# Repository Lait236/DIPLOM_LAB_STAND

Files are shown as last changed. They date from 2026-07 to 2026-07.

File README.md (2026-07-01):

В DIPLOM_LAB_STAND_SCHEMES находятся принципиальные схемы стенда и разводки плат в вариантах с модулями (с использованием заливки земли полигоном ..._gnd или без заливки) и без них (тоже с заливкой полигоном и без неё).

DIPLOM.kicad_sch - Принципиальная схема управляющей платы.

пс_плата_2.kicad_sch - Принципиальная платы расширенной периферии.

DIPLOM.kicad_pcb - Разводка управляющей платы.

DIPLOM_BOARD2.kicad_pcb - Разводка платы расширенной периферии.

В DIPLOM_LAB_STAND находятся файлы проекта для Microchip Studio. 

В DEBUG находится .hex файл для прошивки микроконтроллера. 

DIPLOM_LAB_STAND.atsln - сам проект.

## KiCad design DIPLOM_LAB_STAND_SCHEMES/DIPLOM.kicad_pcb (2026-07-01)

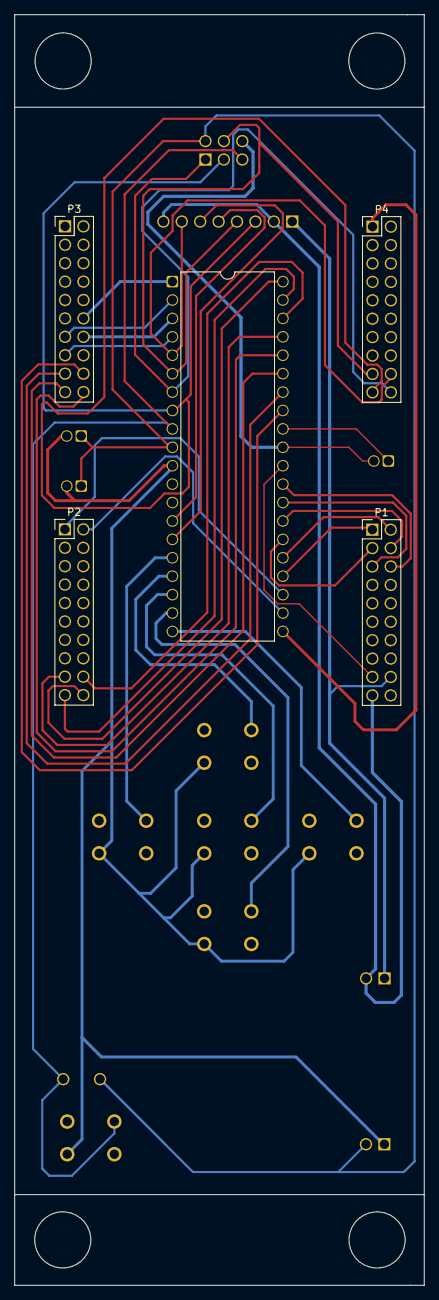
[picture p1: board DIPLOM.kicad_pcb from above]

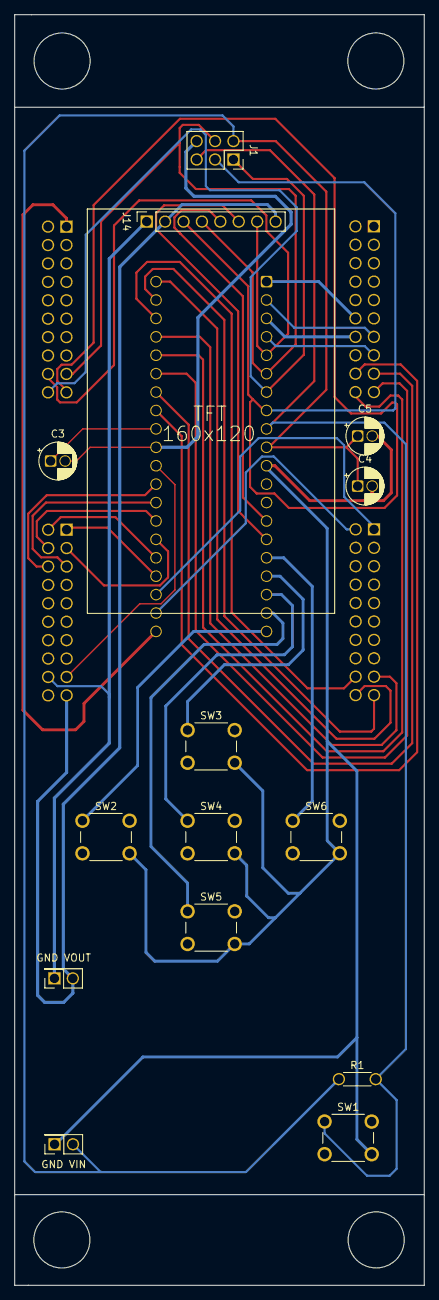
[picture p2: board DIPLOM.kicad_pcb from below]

Board: 2 copper layers, 56.5 x 150.0 mm, 19 parts (14 on the bottom side), 37 nets.

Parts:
C3, C5: 0.1uF; CP_Radial_D5.0mm_P2.00mm
C4: 10uF; CP_Radial_D5.0mm_P2.00mm
GND VIN: PinSocket_2x01_P2.54mm_Vertical
GND VOUT: PinSocket_2x01_P2.54mm_Vertical
J1: USBASP_PINS; PinSocket_2x03_P2.54mm_Vertical
J14: display_out; PinSocket_1x08_P2.54mm_Vertical
P1, P2, P3, P4: PinHeader_2x10_P2.54mm_Vertical
R1: 10k; R_Axial_DIN0204_L3.6mm_D1.6mm_P5.08mm_Horizontal
SW1: BTN_RST; SW_PUSH_6mm
SW2: BTN_L; SW_PUSH_6mm
SW3: BTN_UP; SW_PUSH_6mm
SW4: BTN_CENTER; SW_PUSH_6mm
SW5: BTN_DOWN; SW_PUSH_6mm
SW6: BTN_R; SW_PUSH_6mm
U5: ATmega1284P-P; DIP-40_W15.24mm

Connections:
+3.3v: GND VOUT.2, J14.2, J14.8, P1.19
+5.0v: C4.1, C5.1, GND VIN.2, J1.2 (VCC), P1.17, R1.1, U5.10 (VCC), U5.30 (AVCC)
GND: C3.2, C4.2, C5.2, GND VIN.1, GND VOUT.1, J1.6 (GND), J14.1, P1.18, SW1.1 (A), SW1.2 (A), SW2.2 (A), SW3.2 (A), SW4.2 (A), SW5.2 (A), SW6.2 (A), U5.11 (GND), U5.31 (GND)
unnamed: J1.1 (MISO), P4.20, U5.7 (PB6)
unnamed: J1.4 (MOSI), J14.4, P4.17, U5.6 (PB5)
unnamed: J1.3 (SCK), J14.3, P4.19, U5.8 (PB7)
unnamed: J1.5 (~RST), R1.2, SW1.1 (A), U5.9 (~RESET)
unnamed: P2.20, U5.40 (PA0)
unnamed: P2.19, U5.39 (PA1)
unnamed: P2.18, U5.38 (PA2)
unnamed: P2.17, U5.37 (PA3)
unnamed: P3.20, U5.36 (PA4)
unnamed: P3.19, U5.35 (PA5)
unnamed: P3.17, U5.34 (PA6)
unnamed: P3.18, U5.33 (PA7)
unnamed: P3.12, U5.1 (PB0)
unnamed: P3.13, U5.2 (PB1)
unnamed: P3.14, U5.3 (PB2)
unnamed: P3.15, U5.4 (PB3)
unnamed: P2.2, U5.22 (PC0)
unnamed: P2.1, U5.23 (PC1)
unnamed: P1.1, U5.24 (PC2)
unnamed: P1.2, U5.25 (PC3)
unnamed: P1.3, U5.26 (PC4)
unnamed: P1.4, U5.27 (PC5)
unnamed: P1.5, U5.28 (PC6)
unnamed: P1.6, U5.29 (PC7)
unnamed: P4.1, U5.21 (PD7)
unnamed: J14.7, P4.18, U5.5 (PB4)
unnamed: J14.5, U5.14 (PD0)
unnamed: J14.6, U5.15 (PD1)
unnamed: C3.1, U5.32 (AREF)
unnamed: SW6.1 (A), SW6.2 (A), U5.16 (PD2)
unnamed: SW3.1 (A), SW3.2 (A), U5.17 (PD3)
unnamed: SW4.1 (A), SW4.2 (A), U5.18 (PD4)
unnamed: SW5.1 (A), SW5.2 (A), U5.19 (PD5)
unnamed: SW2.1 (A), SW2.2 (A), U5.20 (PD6)

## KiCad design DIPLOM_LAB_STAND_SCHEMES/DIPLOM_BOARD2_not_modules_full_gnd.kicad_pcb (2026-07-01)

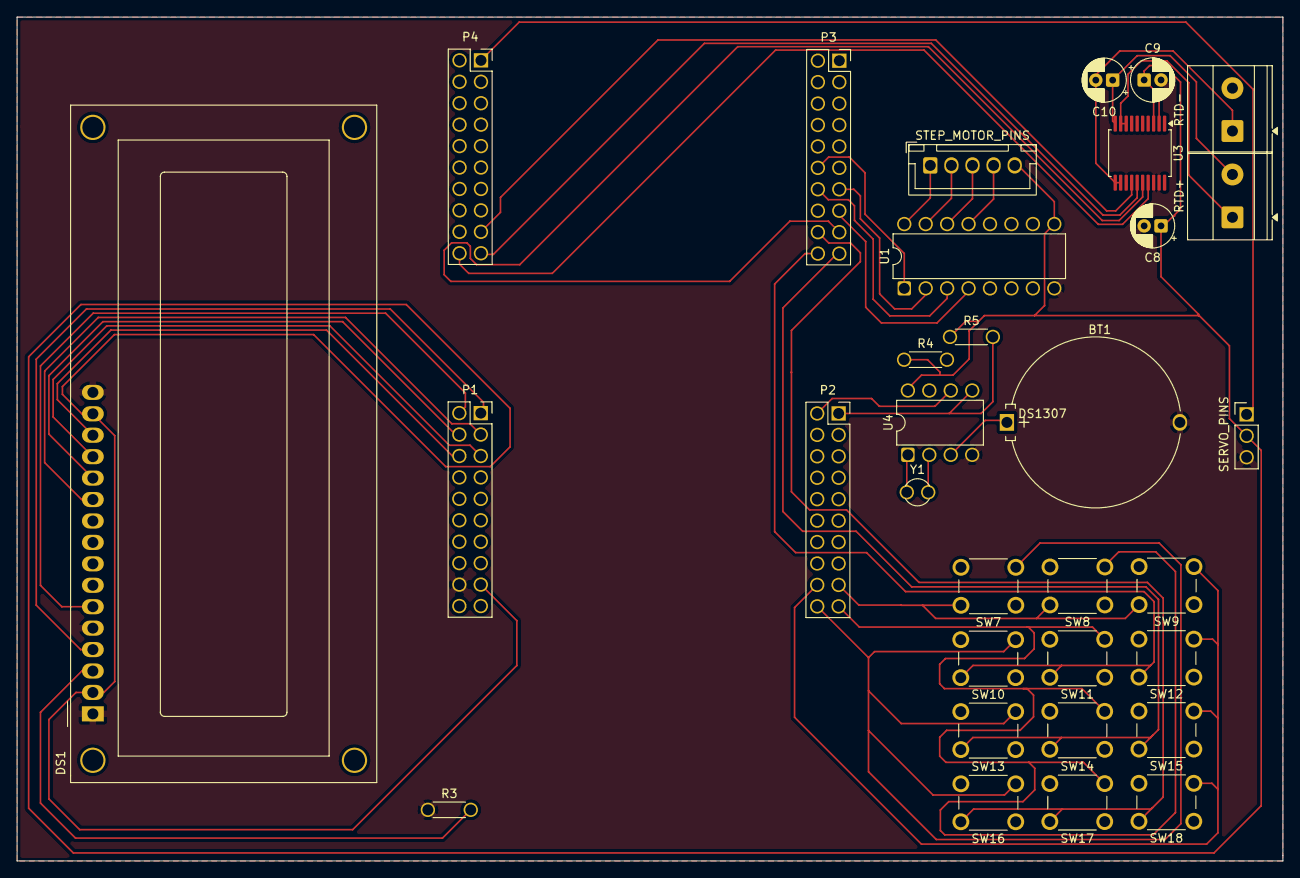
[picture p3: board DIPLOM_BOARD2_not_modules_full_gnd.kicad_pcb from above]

Board: 2 copper layers, 150.0 x 100.0 mm, 32 parts (0 on the bottom side), 33 nets.

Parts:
BT1: Battery 3V; Battery_Panasonic_CR2032-HFN_Horizontal_CircularHoles
C8, C9: 0.1uF; CP_Radial_D5.0mm_P2.00mm
C10: 100nF; CP_Radial_D5.0mm_P2.00mm
DS1: WC1602A
P1, P2, P3, P4: PinSocket_2x10_P2.54mm_Vertical
R3: 2k; R_Axial_DIN0204_L3.6mm_D1.6mm_P5.08mm_Horizontal
R4, R5: 4.7k; R_Axial_DIN0204_L3.6mm_D1.6mm_P5.08mm_Horizontal
RTD+: TerminalBlock_Phoenix_MKDS-1,5-2-5.08_1x02_P5.08m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; TerminalBlock_Phoenix_MKDS-1,5-2-5.08_1x02_P5.08mm_Horizont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
RTD-: TerminalBlock_Phoenix_MKDS-1,5-2-5.08_1x02_P5.08m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; TerminalBlock_Phoenix_MKDS-1,5-2-5.08_1x02_P5.08mm_Horizont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
SERVO_PINS: PinHeader_1x03_P2.54mm_Vertical
STEP_MOTOR_PINS: JST_XH_B5B-XH-A_1x05_P2.50mm_Vertical
SW7: 1; SW_PUSH_6mm
SW8: 2; SW_PUSH_6mm
SW9: 3; SW_PUSH_6mm
SW10: 4; SW_PUSH_6mm
SW11: 5; SW_PUSH_6mm
SW12: 6; SW_PUSH_6mm
SW13: 7; SW_PUSH_6mm
SW14: 8; SW_PUSH_6mm
SW15: 9; SW_PUSH_6mm
SW16: *; SW_PUSH_6mm
SW17: 0; SW_PUSH_6mm
SW18: #; SW_PUSH_6mm
U1: ULN2003; DIP-16_W7.62mm
U3: MAX31865xAP; SSOP-20_5.3x7.2mm_P0.65mm
U4: DS1307; DIP-8_W7.62mm
Y1: 32.768kHz; Crystal_AT310_D3.0mm_L10.0mm_Vertical

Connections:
+5.0v: C8.1, C9.1, DS1.2 (VDD), DS1.15 (LED(+)), P1.17, R4.1, R5.1, SERVO_PINS.2, STEP_MOTOR_PINS.5, U1.9 (COM), U3.2 (DVDD), U3.3 (VDD), U4.8 (VCC)
GND: BT1.2 (-), C8.2, C9.2, DS1.1 (VSS), DS1.5 (R/W), DS1.16 (LED(-)), P1.18, R3.1, SERVO_PINS.3, U1.8 (GND), U3.13 (GND), U3.18 (DGND), U3.19 (GND), U4.4 (GND)
unnamed: BT1.1 (+), U4.3 (VBAT)
unnamed: DS1.3 (VO), R3.2
unnamed: P4.20, U3.17 (SDO)
unnamed: P4.17, U3.14 (SDI)
unnamed: P4.19, U3.15 (SCLK)
unnamed: P2.20, SW7.2 (A), SW10.2 (A), SW13.2 (A), SW16.2 (A)
unnamed: P2.19, SW8.2, SW11.2, SW14.2, SW17.2
unnamed: P2.18, SW9.2, SW12.2, SW15.2, SW18.2
unnamed: P2.17, SW7.1 (A), SW8.1, SW9.1
unnamed: P3.20, SW10.1 (A), SW11.1, SW12.1
unnamed: P3.19, SW13.1 (A), SW14.1, SW15.1
unnamed: P3.18, SW16.1 (A), SW17.1, SW18.1
unnamed: P3.17, U3.16 (~CS)
unnamed: P3.12, U1.1 (I1)
unnamed: P3.13, U1.2 (I2)
unnamed: P3.14, U1.3 (I3)
unnamed: P3.15, U1.4 (I4)
unnamed: P2.2, R4.2, U4.6 (SCL)
unnamed: P2.1, R5.2, U4.5 (SDA)
unnamed: DS1.4 (RS), P1.1
unnamed: DS1.6 (E), P1.2
unnamed: DS1.11 (D4), P1.3
unnamed: DS1.12 (D5), P1.4
unnamed: DS1.13 (D6), P1.5
unnamed: DS1.14 (D7), P1.6
unnamed: P4.1, SERVO_PINS.1
unnamed: U3.4 (BIAS), U3.5 (REFIN+), U3.6 (REFIN-), U3.7 (ISENSOR)
unnamed: C10.1, RTD+.1, RTD+.2, U3.8 (FORCE+), U3.9 (FORCE2), U3.10 (RTDIN+)
unnamed: C10.2, RTD-.1, U3.11 (RTDIN-), U3.12 (FORCE-)
unnamed: U4.1 (X1), Y1.1
unnamed: U4.2 (X2), Y1.2

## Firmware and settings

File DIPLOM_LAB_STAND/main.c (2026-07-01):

/*
 * keybard_display_coderev.c
 *
 * Created: 02.04.2026 22:18:46
 * author : Владислав
 */ 

// подключаем заголовочные файлы

#include "main.h" // основная инициализация
#include "font/font_5x7.h" // таблицы для шрифта
#include "lcd/lcd.h" // подключение заголовочного файла для работы дисплея
#include "nav_buttons/nav_buttons.h" // подключение заголовочного файла для работы управляющих кнопок
#include "keyboard/keyboard.h" // подключение заголовочного файла для работы клавиатуры
#include "menus/menu_board_2/menu_board_2.h" // подключение заголовочного файла для работы меню второй платы
#include "screens/home/home_screen.h" // подключение заголовочного файла для работы главного экрана
#include "screens/board_select/board_select.h" // подключение заголовочного файла для работы экрана выбора плат
#include "screens/keyboard_test/keyboard_test.h" // подключение заголовочного файла для работы окна с тестом клавиатуры
#include "servo/servo.h" // подключение заголовочного файла для работы с сервоприводом
#include "screens/servo_test/servo_test.h" // подключение заголовочного файла для работы окна с тестом сервопривода
#include "stepmotor/stepmotor.h" // подключение заголовочного файла для работы с шаговым мотором
#include "screens/stepper_test/stepper_test.h" // подключение заголовочного файла для работы окна с тестом шагового мотора
#include "menus/menu_board_1/menu_board_1.h" // подключение заголовочного файла для работы меню первой платы
#include "seven_segment/seven_segment.h" // подключение заголовочного файла для работы с семисегментными индикаторами
#include "screens/seven_segment_test/seven_segment_test.h" // подключение заголовочного файла для работы окна с тестом семисегментных индикаторов
#include "led_bar/led_bar.h" // подключение заголовочного файла для работы с 8 светодиодами
#include "screens/led_bar_test/led_bar_test.h" // подключение заголовочного файла для работы окна с тестом 8 светодиодов
#include "speaker/speaker.h" // подключение заголовочного файла для работы со спикером
#include "screens/speaker_test/speaker_test.h" // подключение заголовочного файла для работы окна с тестом спикера
#include "twi/twi.h" // подключение заголовочного файла для работы I2C
#include "rtc/rtc.h" // подключение заголовочного файла для работы DS1307
#include "lcd16x2/lcd1602.h" // подключение заголовочного файла для работы c lcd 16x2
#include "screens/rtc_test/rtc_test.h" // подключение заголовочного файла экрана теста DS1307 (часов реального времени)
#include "screens/temp_lcd_test/temp_lcd_test.h" // подключение заголовочного файла экрана теста MAX31865 и LCD 16x2


// переменные для управления меню

uint8_t menu_selected = 0; // индекс выбранного пункта меню, 0 — первый пункт, 1 — второй пункт и так далее

uint8_t menu_top = 0; // индекс верхнего видимого пункта меню нужен для скролла например, если menu_top = 1, то первым на экране будет пункт с индексом 1

uint8_t screen_mode = SCREEN_HOME; // текущий режим экрана

uint8_t board_selected = 0; // выбранная плата на экране выбора платы, 0 — плата номер 1, 1 — плата номер 2

// настройки двойного нажатия центральной кнопки

#define CENTER_DOUBLE_TIMEOUT_COUNT 30 // сколько раз проверяем второе нажатие центральной кнопки

#define CENTER_DOUBLE_POLL_DELAY_MS 10 // пауза между проверками второго нажатия

// проверка второго нажатия центральной кнопки

uint8_t center_button_double_pressed(void)
{
	uint8_t i; // счётчик попыток ожидания

	char second_key; // здесь будет вторая прочитанная кнопка

	for (i = 0; i < CENTER_DOUBLE_TIMEOUT_COUNT; i++)
	{
		_delay_ms(CENTER_DOUBLE_POLL_DELAY_MS); // маленькая пауза между проверками

		second_key = nav_buttons_get_key(); // снова читаем навигационные кнопки

		if (second_key == '5')
		{
			// если второй раз нажали центральную кнопку, значит это двойное нажатие

			return 1;
		}

		if (second_key != KEY_NONE)
		{
			// если нажали не центральную кнопку, значит это уже не двойное нажатие 5

			return 0;
		}
	}

	return 0; // второго нажатия 5 не было
}

// функция настройки аппаратного SPI

void spi_init(void)
{
	
	// регистр управления SPI SPCR
	// значение SPE = 1 — включить SPI
	// значение MSTR = 1 — режим Master
	// биты SPR0 и SPR1 сброшены для минимального базового делителя
	SPCR = (1 << SPE) | (1 << MSTR);

	// регистр состояния SPI SPSR
	// значение SPI2X = 1 — включить двойную скорость
	// при F_CPU = 8 МГц скорость SPI будет F_CPU / 2 = 4 МГц
	SPSR = (1 << SPI2X);

}

// отключаем системный делитель частоты

void clock_init(void)
{
	CLKPR = (1 << CLKPCE);// разрешаем изменение делителя частоты
	CLKPR = 0;
}

int main(void)
{
	clock_init(); // отключаем делитель частоты

	lcd_port_init(); // настраиваем порты дисплея

	spi_init(); // настраиваем SPI

	nav_buttons_init(); // инициализация пяти управляющих кнопок

	keypad_init(); // настраиваем клавиатуру

	lcd_init(); // инициализируем дисплей
	
	lcd1602_init(); // один раз инициализируем LCD 16x2

	lcd1602_off(); // выключаем отображение LCD 16x2
	
	sei(); // разрешаем глобальные прерывания

	screen_mode = SCREEN_HOME; // начинаем с главного экрана

	screen_home_start(); // рисуем главный экран

	while (1)
	{
		// читаем пять навигационных кнопок
		// они возвращают виртуальные клавиши:
		// '2' — вверх
		// '8' — вниз
		// '4' — влево
		// '6' — вправо
		// '5' — центр
		char key = nav_buttons_get_key();

		if (screen_mode == SCREEN_HOME)
		{
			// если открыт главный экран

			screen_home_key(key); // передаём кнопку главному экрану
		}

		else if (screen_mode == SCREEN_BOARD_SELECT)
		{
			// если открыт экран выбора платы

			if (key == '5')
			{
				// если нажата центральная кнопка,
				// сначала проверяем:
				// это одиночное нажатие или двойное

				if (center_button_double_pressed())
				{
					// если было двойное нажатие 55, возвращаемся на главный экран

					screen_mode = SCREEN_HOME; // меняем режим экрана

					screen_home_start(); // рисуем главный экран
				}
				else
				{
					// если второго нажатия не было, значит это обычный выбор платы

					screen_board_select_key(key); // передаём одиночную 5 экрану выбора плат
				}
			}
			else
			{
				// если нажата не центральная кнопка, просто передаём её экрану выбора плат

				screen_board_select_key(key);
			}
		}
		
		else if (screen_mode == SCREEN_BOARD1_MENU)
		{
			// если открыто меню платы номер 1

			if (key == '2')
			{
				// верхняя кнопка, двигаем выделение меню вверх

				uint8_t old_selected = menu_board_1_get_selected(); // запоминаем старый выбранный пункт

				menu_board_1_up(); // перемещаем выделение вверх

				menu_board_1_draw_item(old_selected); // перерисовываем старый пункт

				menu_board_1_draw_item(menu_board_1_get_selected()); // перерисовываем новый выбранный пункт
			}

			if (key == '8')
			{
				// нижняя кнопка, двигаем выделение меню вниз

				uint8_t old_selected = menu_board_1_get_selected(); // запоминаем старый выбранный пункт

				menu_board_1_down(); // перемещаем выделение вниз

				menu_board_1_draw_item(old_selected); // перерисовываем старый пункт

				menu_board_1_draw_item(menu_board_1_get_selected()); // перерисовываем новый выбранный пункт
			}
			
			if (key == '5')
			{
				// центральная кнопка
				// в меню платы №1:
				// одиночное 5 — открыть пункт меню
				// двойное 55 — вернуться на экран выбора плат

				if (center_button_double_pressed())
				{
					// если было двойное нажатие 55, возвращаемся на экран выбора плат

					screen_mode = SCREEN_BOARD_SELECT;	// меняем режим экрана

					screen_board_select_start(); // рисуем экран выбора плат
				}
				else
				{
					// если второго нажатия не было, значит это обычный выбор пункта меню

					if (menu_board_1_get_selected() == BOARD1_MENU_ITEM_SEVEN_SEGMENT_TEST)
					{
						// если выбран первый пункт:
						// "ТЕСТ 7 СЕГМ"

						screen_mode = SCREEN_SEVEN_SEGMENT_TEST; // переходим в экран теста семисегментных индикаторов

						screen_seven_segment_test_start(); // открываем экран теста
					}

					else if (menu_board_1_get_selected() == BOARD1_MENU_ITEM_LED_BAR_TEST)
					{
						// если выбран второй пункт:
						// "ТЕСТ ДИОДОВ"

						screen_mode = SCREEN_LED_BAR_TEST; // переходим в экран теста 8 светодиодов

						screen_led_bar_test_start(); // открываем экран теста
					}

					else if (menu_board_1_get_selected() == BOARD1_MENU_ITEM_SPEAKER_TEST)
					{
						// если выбран третий пункт:
						// "ТЕСТ СПИКЕРА"

						screen_mode = SCREEN_SPEAKER_TEST; // переходим в экран теста спикера

						screen_speaker_test_start(); // открываем экран теста
					}
				}
			}
		}

		else if (screen_mode == SCREEN_BOARD2_MENU)
		{
			// если открыто меню платы номер 2

			if (key == '2')
			{
				// верхняя кнопка, двигаем выделение меню вверх

				uint8_t old_selected = menu_selected; // запоминаем старый выбранный пункт

				uint8_t old_top = menu_top; // запоминаем старую верхнюю позицию меню

				menu_up(); // меняем выбранный пункт вверх

				if (old_top != menu_top)
				{
					// если меню прокрутилось, перерисовываем всё меню

					menu_draw();
				}
				else
				{
					// если прокрутки не было, перерисовываем только два пункта

					menu_draw_item(old_selected); // старый выбранный пункт

					menu_draw_item(menu_selected); // новый выбранный пункт
				}
			}

			if (key == '8')
			{
				// нижняя кнопка, двигаем выделение меню вниз

				uint8_t old_selected = menu_selected; // запоминаем старый выбранный пункт

				uint8_t old_top = menu_top; // запоминаем старую верхнюю позицию меню

				menu_down(); // меняем выбранный пункт вниз

				if (old_top != menu_top)
				{
					// если меню прокрутилось, перерисовываем всё меню

					menu_draw();
				}
				else
				{
					// если прокрутки не было, перерисовываем только два пункта

					menu_draw_item(old_selected); // старый выбранный пункт

					menu_draw_item(menu_selected); // новый выбранный пункт
				}
			}

			if (key == '5')
			{
				// центральная кнопка
				// в меню платы №2:
				// одиночное 5 — открыть пункт меню
				// двойное 55 — вернуться на экран выбора плат

				if (center_button_double_pressed())
				{
					// если было двойное нажатие 55, возвращаемся на экран выбора плат

					screen_mode = SCREEN_BOARD_SELECT; // меняем режим экрана

					screen_board_select_start(); // рисуем экран выбора плат
				}
				else
				{
					// если второго нажатия не было, значит это обычный выбор пункта меню

					if (menu_selected == MENU_ITEM_KEYBOARD_TEST)
					{
						// выбран тест клавиатуры

						screen_mode = SCREEN_KEYBOARD_TEST; // переходим в экран теста клавиатуры

						screen_keypad_test_start(); // рисуем экран теста клавиатуры
					}

					else if (menu_selected == MENU_ITEM_SERVO_TEST)
					{
						// выбран тест сервопривода

						screen_mode = SCREEN_SERVO_TEST; // переходим в экран теста сервопривода

						screen_servo_test_start(); // рисуем экран теста сервопривода
					}

					else if (menu_selected == MENU_ITEM_STEPPER_TEST)
					{
						// выбран тест шагового мотора

						screen_mode = SCREEN_STEPPER_TEST; // переходим в экран теста шагового мотора

						screen_stepper_test_start(); // рисуем экран теста шагового мотора
					}
					
					
					else if (menu_selected == MENU_ITEM_TEMP_LCD_TEST)
					{
						// выбран четвёртый пункт:
						// модуль MAX31865 + LCD 16x2

						screen_mode = SCREEN_TEMP_LCD_TEST; // переходим в экран теста lcd и max31865

						screen_temp_lcd_test_start(); // открываем экран теста lcd и max31865
					}

					else if (menu_selected == MENU_ITEM_RTC_TEST)
					{
						// выбран пятый пункт:
						// тест часов реального времени DS1307

						screen_mode = SCREEN_RTC_TEST; // переходим в экран теста DS1307

						screen_rtc_test_start(); // открываем экран теста DS1307
					}

				}
			}
		}
		
		else if (screen_mode == SCREEN_SEVEN_SEGMENT_TEST)
		{
			// если открыт тест семисегментных индикаторов

			screen_seven_segment_test_key(key); // передаём управляющую кнопку экрану теста
		}
		
		else if (screen_mode == SCREEN_LED_BAR_TEST)
		{
			// если открыт тест 8 светодиодов

			screen_led_bar_test_key(key); // передаём управляющую кнопку экрану теста
		}
		
		else if (screen_mode == SCREEN_SPEAKER_TEST)
		{
			// если открыт тест спикера

			screen_speaker_test_key(key); // передаём управляющую кнопку экрану теста
		}

		else if (screen_mode == SCREEN_KEYBOARD_TEST)
		{
			// если открыт тест клавиатуры

			screen_keypad_test_key(key); // передаём управляющую кнопку экрану теста клавиатуры, сама клавиатура 4x3 читается внутри keyboard_test.c
		}

		else if (screen_mode == SCREEN_SERVO_TEST)
		{
			// если открыт тест сервопривода

			screen_servo_test_key(key); // передаём управляющую кнопку экрану теста сервопривода
		}

		else if (screen_mode == SCREEN_STEPPER_TEST)
		{
			// если открыт тест шагового мотора

			screen_stepper_test_key(key); // передаём управляющую кнопку экрану теста шагового мотора
		}
		
		else if (screen_mode == SCREEN_RTC_TEST)
		{
			// если открыт тест DS1307

			screen_rtc_test_key(key); // передаём управляющую кнопку экрану теста часов
		}
		
		else if (screen_mode == SCREEN_TEMP_LCD_TEST)
		{
			screen_temp_lcd_test_key(key); // передаём управляющую кнопку экрану теста MAX31865 и lcd16x2
		}
	}
}

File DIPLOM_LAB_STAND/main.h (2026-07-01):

	/*
 * main.h
 *
 * Created: 02.04.2026 22:29:26
 *  Author: Владислав
 */ 


#ifndef MAIN_H_
#define MAIN_H_

// установка частоты

#define F_CPU 8000000UL

// подключение системных файлов библиотек

#include <avr/io.h> // стандартная библиотека инициализации AVR
#include <util/delay.h> // задержки
#include <stdint.h> // фиксированные целочисленные типы
#include <avr/pgmspace.h> // работа с памятью программ Flash || PROGMEM хранит большие таблицы не в SRAM, а во Flash, так как SRAM мало || обращение к Flash памяти идет через оператор &
#include <avr/interrupt.h> // работа с прерываниями

// замена имен лапок на макроподстановки для удобной инициализации spi для дисплея

#define LCD_SCK  PB7 // пин тактового сигнала SPI
#define LCD_MOSI PB5 // пин MOSI SPI
#define LCD_CS   PB4 // пин Chip Select дисплея подключён к PB2 || 0 — дисплей выбран и слушает SPI || 1 — дисплей игнорирует SPI
#define LCD_DC   PD1 // пин DC дисплея подключён к PD1 || DC = Data / Command || 0 — отправляем команду || 1 — отправляем данные
#define LCD_RST  PD0 // пин аппаратного сброса дисплея подключён к PD0

// назначение для отрисовки на дисплее

#define LCD_XSTART 0 // смещение по X (LCD_XSTART поправка по горизонтали)
#define LCD_YSTART 0 // смещение по Y (LCD_YSTART поправка по вертикали)
#define LCD_MADCTL 0xC0 // значение для команды MADCTL || оно управляет ориентацией экрана и порядком обхода памяти(описание приведено в документации на ST7735)

// макроподстановки для цветов в формате RGB565 (начальная палитра || сайт для подбора значения цветов в формате RGB565:https://rgbcolorpicker.com/565)

#define COLOR_BLACK  0x0000 // чёрный цвет
#define COLOR_WHITE  0xFFFF // белый цвет
#define COLOR_RED    0xF800 // красный цвет
#define COLOR_GREEN  0x07E0 // зелёный цвет
#define COLOR_BLUE   0x001F // синий цвет
#define COLOR_YELLOW 0xFFE0 // жёлтый цвет

// крестовина для управления системой

#define BTN_LEFT   PD2 // левая кнопка
#define BTN_UP     PD3 // верхняя кнопка
#define BTN_CENTER PD4 // центральная кнопка
#define BTN_DOWN   PD5 // нижняя кнопка
#define BTN_RIGHT  PD6 // правая кнопка


// макроподстановка для клавиатуры

#define KEY_NONE 0 // значение, которое возвращает клавиатура, если кнопка не нажата

// макроподстановки для режимов экранов

#define SCREEN_HOME           0 // главный экран
#define SCREEN_BOARD_SELECT   1 // экран выбора платы
#define SCREEN_BOARD2_MENU    2 // меню платы №2
#define SCREEN_KEYBOARD_TEST  3 // тест клавиатуры
#define SCREEN_SERVO_TEST     4 // тест сервопривода
#define SCREEN_STEPPER_TEST   5 // тест шагового мотора
#define SCREEN_BOARD1_MENU    6 // меню платы №1
#define SCREEN_SEVEN_SEGMENT_TEST 7 // экран теста семисегментных индикаторов
#define SCREEN_LED_BAR_TEST 8 // экран теста 8 светодиодов
#define SCREEN_SPEAKER_TEST 9 // экран теста спикера
#define SCREEN_RTC_TEST 10 // экран теста часов реального времени
#define SCREEN_TEMP_LCD_TEST 11 // экран теста MAX31865 и LCD 16x2

// макроподстановки для меню платы №1

#define BOARD1_MENU_COUNT 3 // общее количество пунктов меню платы №1
#define BOARD1_MENU_VISIBLE 3 // количество пунктов меню, которые одновременно видны на экране

// макроподстановки для пунктов меню платы №1

#define BOARD1_MENU_ITEM_SEVEN_SEGMENT_TEST 0 // первый пункт меню платы №1: тест семисегментных индикаторов
#define BOARD1_MENU_ITEM_LED_BAR_TEST 1 // второй пункт меню платы №1: тест 8 светодиодов
#define BOARD1_MENU_ITEM_SPEAKER_TEST 2 // третий пункт меню платы №1: тест спикера

// макроподстановки для меню платы №2

#define MENU_COUNT 5 // общее количество пунктов меню платы №2
#define MENU_VISIBLE 4 // количество пунктов меню, которые одновременно видны на экране

// макроподстановки для пунктов меню платы №2

#define MENU_ITEM_KEYBOARD_TEST 0 // первый пункт меню платы №2: тест клавиатуры
#define MENU_ITEM_SERVO_TEST    1 // второй пункт меню платы №2: тест сервопривода
#define MENU_ITEM_STEPPER_TEST 2 // третий пункт меню платы №2: тест шагового мотора
#define MENU_ITEM_TEMP_LCD_TEST 3 // четвертый пункт меню платы №2: тест MAX31865 и LCD 16x2
#define MENU_ITEM_RTC_TEST 4 // пятый пункт меню платы №2: тест DS1307 (часов реального времени)

// объявления глобальных переменные для управления меню

extern uint8_t menu_selected;
extern uint8_t menu_top;
extern uint8_t screen_mode;

#endif /* MAIN_H_ */

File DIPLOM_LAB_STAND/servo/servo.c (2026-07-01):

/*
 * servo.c
 *
 * Created: 14.04.2026 22:58:10
 *  Author: Владислав
 */

#include "../main.h"
#include "servo.h"
#include <util/atomic.h>

#define SERVO_PIN PD7 // вывод PD7 — физический пин 21 ATmega1284P на этот пин будет идти сигнал управления сервой

#define SERVO_MIN_PULSE 800 // минимальный импульс сервопривода в микросекундах

#define SERVO_MAX_PULSE 2400 // максимальный импульс сервопривода в микросекундах

#define SERVO_PERIOD 20000 // период сигнала сервопривода в микросекундах 20000 мкс = 20 мс = 50 Гц

#define SERVO_STEP 5 // шаг поворота сервопривода в градусах за одно нажатие кнопки

#define SERVO_TIMER_TICKS_PER_US 1 // количество тиков Timer1 в одной микросекунде

static uint8_t servo_angle = 90; // текущий угол сервопривода начинаем с 90 градусов, то есть примерно с середины

static volatile uint16_t servo_pulse_us = 1500; // текущая длительность высокого импульса в микросекундах модификатор volatile нужен, потому что переменная используется и в основном коде, и в прерывании

static volatile uint8_t servo_phase = 0; // фаза сигнала: 0 — начать высокий импульсь, 1 — закончить высокий импульс

// инициализируем управление сервоприводом

void servo_init(void)
{
	DDRD |= (1 << SERVO_PIN); // вывод PD7 становится выходом

	PORTD &= ~(1 << SERVO_PIN); // сначала ставим PD7 в 0

	TCCR1A = 0; // очищаем регистр настройки Timer1 A

	TCCR1B = 0; // очищаем регистр настройки Timer1 B

	TIMSK1 = 0; // запрещаем прерывания Timer1, пока настраиваем таймер

	TCNT1 = 0; // сбрасываем счётчик Timer1

	OCR1A = 100; // первое короткое значение сравнения, после него начнётся первый импульс

	TCCR1B |= (1 << WGM12); // включаем режим CTC Timer1 таймер считает до OCR1A, вызывает прерывание и сбрасывается

	TCCR1B |= (1 << CS11); // запускаем Timer1 с делителем 8

	TIFR1 = (1 << OCF1A); // сбрасываем флаг совпадения Timer1 Compare A

	TIMSK1 |= (1 << OCIE1A); // разрешаем прерывание Timer1 Compare A

	servo_phase = 0; // начинаем с фазы старта импульса

	// устанавливаем угол сервопривода
	servo_set_angle(90); // ставим сервопривод в среднее положение
}

// задаём длительность управляющего импульса в микросекундах

static void servo_set_pulse_us(uint16_t pulse_us)
{
	if (pulse_us < SERVO_MIN_PULSE)
	{
		pulse_us = SERVO_MIN_PULSE;
	}
	// если значение слишком маленькое, ограничиваем его безопасным минимумом

	if (pulse_us > SERVO_MAX_PULSE)
	{
		pulse_us = SERVO_MAX_PULSE;
	}
	// если значение слишком большое, ограничиваем его безопасным максимумом

	ATOMIC_BLOCK(ATOMIC_RESTORESTATE)
	{
		servo_pulse_us = pulse_us;
	}
}

// задаем угол

void servo_set_angle(uint8_t angle)
{
	uint16_t pulse; // здесь будет рассчитанная длительность импульса

	if (angle > 180)
	{
		angle = 180;
	}
	// ограничиваем угол диапазоном 0..180 градусов

	servo_angle = angle; // запоминаем текущий угол

	pulse = SERVO_MIN_PULSE; // начинаем с минимального импульса

	pulse += ((uint32_t)(SERVO_MAX_PULSE - SERVO_MIN_PULSE) * (180 - angle)) / 180; // переводим угол в длительность импульса:
	// значение ANGLE = 0   -> 600 мкс
	// значение ANGLE = 90  -> 1500 мкс
	// значение ANGLE = 180 -> 2400 мкс

	servo_set_pulse_us(pulse); // передаём рассчитанный импульс в генератор сигнала
}

// поворачиваем сервопривод влево на один шаг

void servo_left(void)
{
	if (servo_angle >= SERVO_STEP)
	{
		servo_angle -= SERVO_STEP;
	}
	else
	{
		servo_angle = 0;
	}

	servo_set_angle(servo_angle);
}

// поворачиваем сервопривод вправо на один шаг

void servo_right(void)
{
	if (servo_angle <= 180 - SERVO_STEP)
	{
		servo_angle += SERVO_STEP;
	}
	else
	{
		servo_angle = 180;
	}

	servo_set_angle(servo_angle);
}

// поворачиваем сервопривод максимально вправо

void max_servo_right(void)
{
	servo_angle = 180;

	servo_set_angle(servo_angle);
}

// возвращаем текущий угол сервопривода

uint8_t servo_get_angle(void)
{
	return servo_angle;
}

// останавливаем сервосигнал

void servo_stop(void)
{
	TIMSK1 &= ~(1 << OCIE1A); // запрещаем прерывание Timer1 Compare A

	TCCR1A = 0; // сбрасываем настройки Timer1 A
	TCCR1B = 0; // останавливаем Timer1

	PORTD &= ~(1 << SERVO_PIN); // вывод PD7 = 0 сигнал сервопривода выключен

	servo_phase = 0; // сбрасываем фазу формирования сигнала
}

// инициализируем прерывание для timer1

ISR(TIMER1_COMPA_vect)
{
	uint16_t pulse_copy; // копия длительности импульса

	uint16_t timer_ticks; // количество тиков Timer1

	if (servo_phase == 0)
	{
		// начинаем высокий импульс сервосигнала

		PORTD |= (1 << SERVO_PIN); // вывод PD7 = 1

		pulse_copy = servo_pulse_us; // берём текущую длительность импульса в микросекундах

		timer_ticks = (uint16_t)((uint32_t)pulse_copy * SERVO_TIMER_TICKS_PER_US); // переводим микросекунды в тики Timer1

		OCR1A = timer_ticks - 1; // следующее прерывание будет через pulse_copy микросекунд

		servo_phase = 1; // следующая фаза — закончить высокий импульс
	}
	else
	{
		// заканчиваем высокий импульс

		PORTD &= ~(1 << SERVO_PIN); // вывод PD7 = 0

		pulse_copy = servo_pulse_us; // берём текущую длительность импульса

		timer_ticks = (uint16_t)((uint32_t)(SERVO_PERIOD - pulse_copy) * SERVO_TIMER_TICKS_PER_US); // считаем остаток периода

		OCR1A = timer_ticks - 1; // ждём остаток периода до 20 мс

		servo_phase = 0; // следующая фаза — начать новый импульс
	}
}

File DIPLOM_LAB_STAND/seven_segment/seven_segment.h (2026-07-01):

/*
 * seven_segment.h
 *
 * Created: 10.05.2026 21:07:24
 *  Author: Владислав
 */ 


#ifndef SEVEN_SEGMENT_H_
#define SEVEN_SEGMENT_H_

#include <stdint.h>

void seven_segment_init(void); // инициализируем семисегментные индикаторы
// сегменты: PORTA
// разряды: PB0, PB1, PB2, PB3

void seven_segment_enable(void); // разрешаем отображение числа
void seven_segment_disable(void); // выключаем все разряды и гасим сегменты
void seven_segment_set_number(uint16_t num); // выводим число 0..9999

void seven_segment_set_digits(uint8_t thousands, uint8_t hundreds, uint8_t tens, uint8_t units); // задаём 4 цифры вручную:
// значение THOUSANDS — тысячи,
// значение HUNDREDS — сотни,
// значение TENS — десятки,
// значение UNITS — единицы


#endif /* SEVEN_SEGMENT_H_ */

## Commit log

2026-07-01 Updated struct
    [DIPLOM-B_Mask.gbr, DIPLOM-B_Paste.gbr, DIPLOM-B_Silkscreen.gbr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]
2026-07-01 Updated README
    Добавлены файлы схем и разводки для управляющей платы и периферии.
